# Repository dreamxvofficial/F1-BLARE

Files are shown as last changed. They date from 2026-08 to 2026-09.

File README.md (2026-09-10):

# F1 BLARE 🏎️⏰

## Inspiration

I wanted to make a BLARE alarm clock, but I didn't want it to look like a normal alarm clock.

Since I really like Formula 1, I decided to design the enclosure around the shape and layout of an F1 steering wheel. The goal was to make something that looks like a small racing control system while still functioning as a practical alarm clock.

The display is placed in the center like the display on an F1 steering wheel, with four buttons around it for controlling the clock and alarms.

The four buttons are used for:

- `+`
- `Set Alarm / Stop Alarm`
- `-`
- `Change Screen`

There are four screens: the normal clock and three different alarm screens.

### Challenges

This was my first time making a PCB and working with KiCad, so there were quite a few things I had to figure out.

I had to learn how to make the schematic, assign footprints, route the PCB, check it with DRC and add 3D models.

One of the biggest challenges was designing the PCB so that all the components, buttons and display connections would fit into a compact enclosure.

I originally planned to use an F1 car model as part of the enclosure, but I changed the design so that the enclosure itself is F1-inspired and can be designed directly as a proper CAD model. This makes the final design easier to manufacture and 3D print.

### Specifications

BOM:

- 1x Seeed XIAO ESP32-C3
- 4x Cherry MX-style switches
- 1x 2.25" TFT display
- 1x 3.3V piezo buzzer
- 1x 8-pin connector for the display
- 8x female-female jumper wires
- 4x M3x8 screws
- 4x M3x16 screws
- 8x M3 heatset inserts

Others:

- Arduino firmware
- Custom PCB
- Custom F1 steering-wheel-inspired enclosure
- 3D printed enclosure

### How it works

The main screen shows the current time.

Pressing the fourth button changes between the clock and the three alarm screens.

On an alarm screen:

- `+` increases the alarm time
- `-` decreases the alarm time
- `Set Alarm` enables/disables the alarm

When an alarm goes off, the buzzer plays until the user presses the alarm button.

The enclosure is designed around an F1 steering wheel layout, with the TFT display positioned in the center and the four physical controls placed around it.

### Schematic

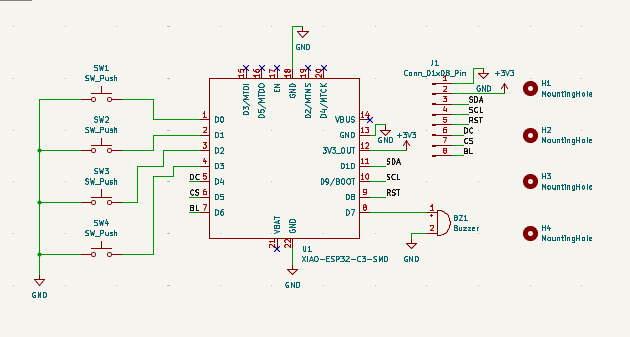
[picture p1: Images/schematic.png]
Schematic


### PCB

| PCB | 3D Model |
| --- | --- |
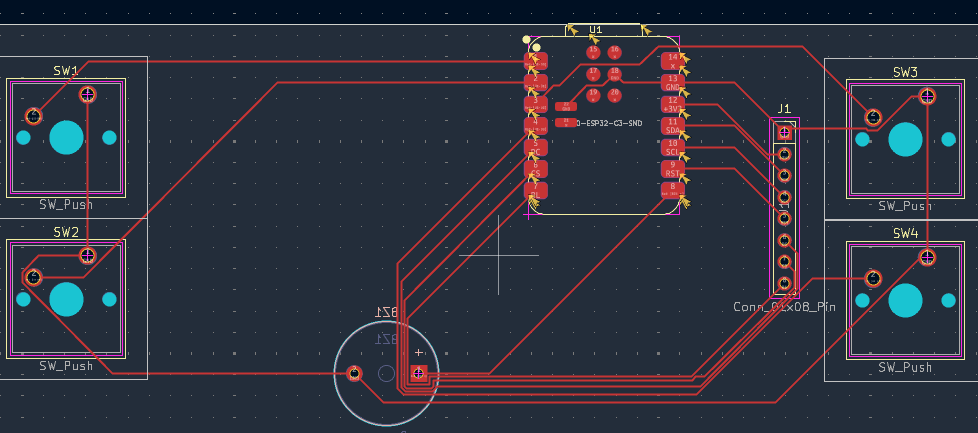
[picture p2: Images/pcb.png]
PCB
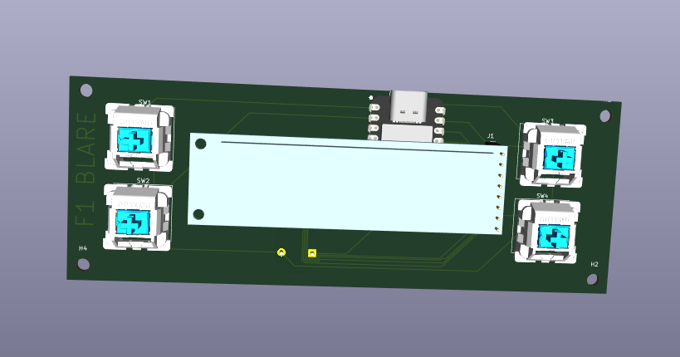
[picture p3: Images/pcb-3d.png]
3D PCB
|  |  |

### Case

The PCB will be mounted inside a custom 3D-printed enclosure inspired by an F1 steering wheel.

The 2.25" TFT display is positioned in the center of the front panel, with the four buttons arranged around it for easy access.

The enclosure will use rounded edges, racing-inspired shapes and details while keeping the internal geometry practical for 3D printing.

Unlike using an imported F1 car STL, the enclosure itself is designed as a proper CAD model so that the dimensions can be matched to the PCB and components.

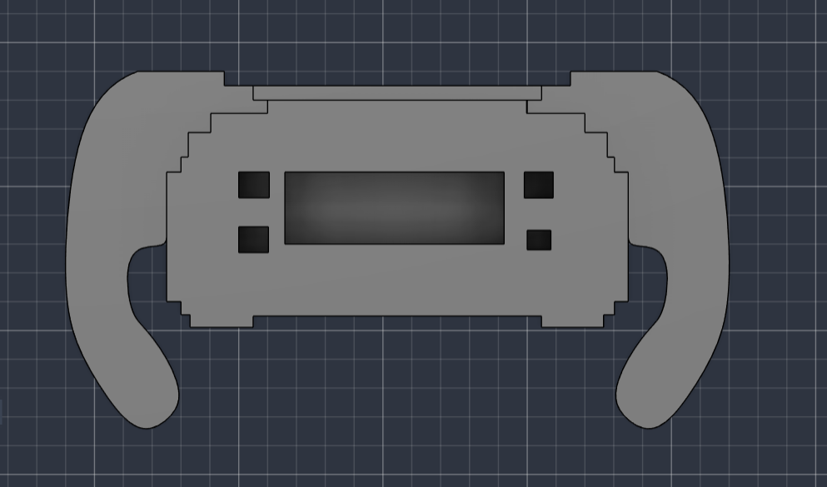
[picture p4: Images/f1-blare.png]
F1 BLARE

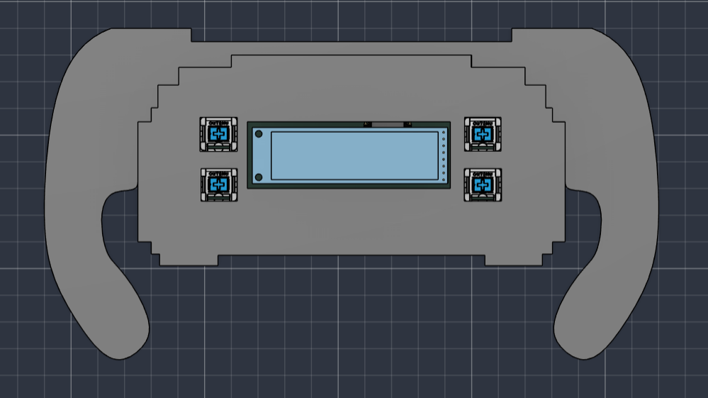
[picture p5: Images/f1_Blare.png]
F1 BLARE


### Firmware

The firmware is written using Arduino IDE and runs on the XIAO ESP32-C3.

The TFT display is controlled using the Adafruit GFX and ST7789 libraries.

The firmware handles:

- Digital clock display
- Three independent alarms
- Alarm time adjustment
- Alarm enable/disable
- Buzzer control
- Screen switching

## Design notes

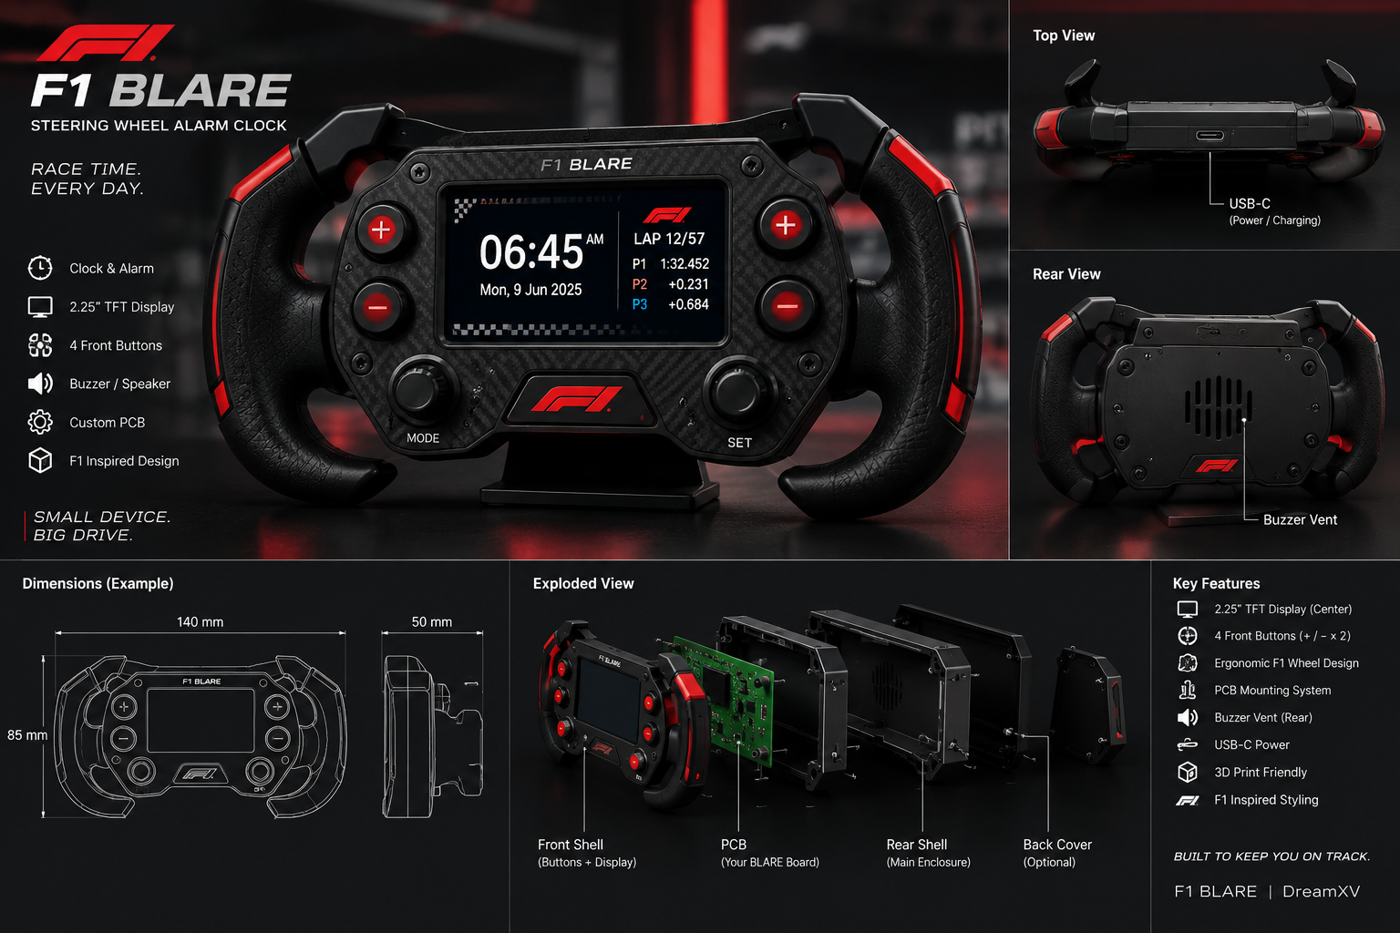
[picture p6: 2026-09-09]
Images/inspo.png

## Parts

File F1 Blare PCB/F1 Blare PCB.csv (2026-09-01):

Reference | Qty | Value | DNP | Exclude from BOM | Exclude from Board | Exclude from Simulation | Exclude from Position Files | Footprint | Datasheet
BZ1 | 1 | Buzzer |  |  |  |  | ${EXCLUDE_FROM_POS_FILES} | Buzzer_Beeper:Buzzer_12x9.5RM7.6
J1 | 1 | Conn_01x08_Pin |  |  |  |  | ${EXCLUDE_FROM_POS_FILES} | Connector_PinSocket_2.54mm:PinSocket_1x08_P2.54mm_Vertical
SW1,SW2,SW3,SW4 | 4 | SW_Push |  |  |  |  | ${EXCLUDE_FROM_POS_FILES} | Button_Switch_Keyboard:SW_Cherry_MX_1.00u_PCB
U1 | 1 | XIAO-ESP32-C3-SMD |  |  |  |  | ${EXCLUDE_FROM_POS_FILES} | Seeed_Studio_XIAO_Series:XIAO-ESP32-C3-SMD

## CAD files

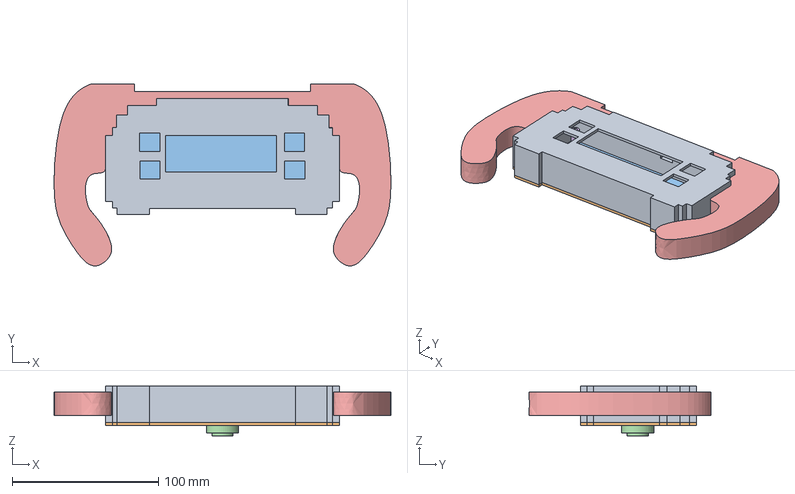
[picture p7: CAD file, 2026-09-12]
Production/CAD_CASE/F1 Blare PCB_Assembly.step
230.1 x 124.1 x 34.0 mm

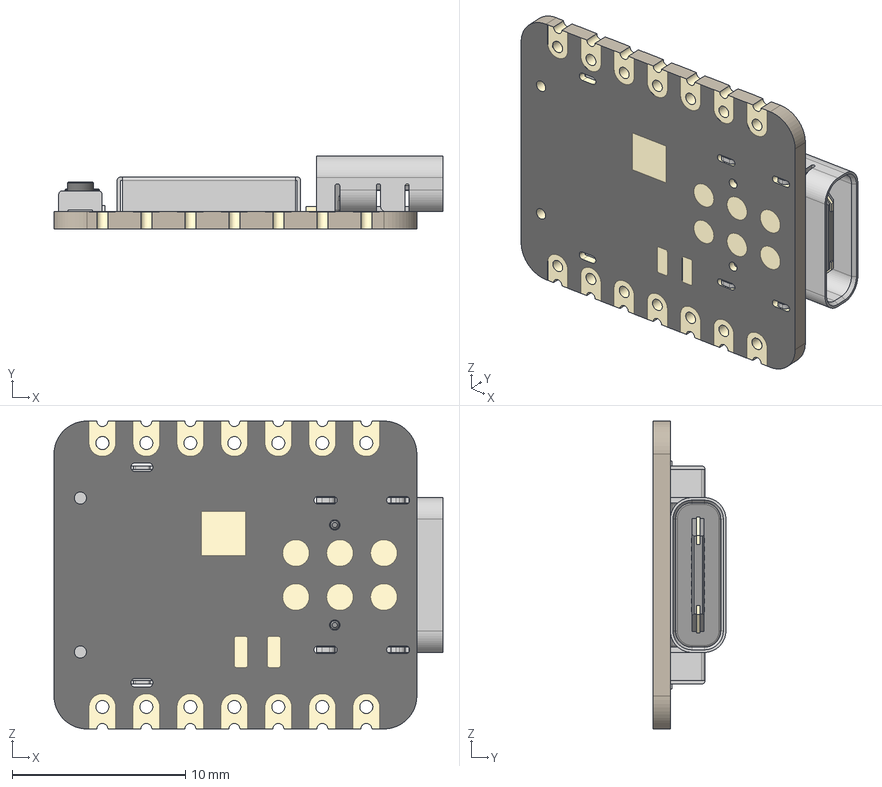
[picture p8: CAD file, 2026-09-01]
Additional Model/ESP 32 C3/Seeed Studio XIAO-ESP32-C3.step
22.5 x 4.21 x 17.8 mm
BOSS-EXTRUDE14_8_
BOSS-EXTRUDE7_4_
BOSS-EXTRUDE7_3_
BOSS-EXTRUDE14_4_
BOSS-EXTRUDE14_2_
BOSS-EXTRUDE14_11_
BOSS-EXTRUDE7_7_
BOSS-EXTRUDE14_9_
BOSS-EXTRUDE14_3_
BOSS-EXTRUDE14_7_
MIRROR2
BOSS-EXTRUDE14_5_
BOSS-EXTRUDE14_12_
BOSS-EXTRUDE7_8_
BOSS-EXTRUDE7_1_
BOSS-EXTRUDE14_10_
BOSS-EXTRUDE7_9_
BOSS-EXTRUDE14_6_
BOSS-EXTRUDE14_1_
BOSS-EXTRUDE7_6_
BOSS-EXTRUDE7_2_
CUT-EXTRUDE5
BOSS-EXTRUDE7_5_
U.FL Connector v1
Button (1) x 2
Shield

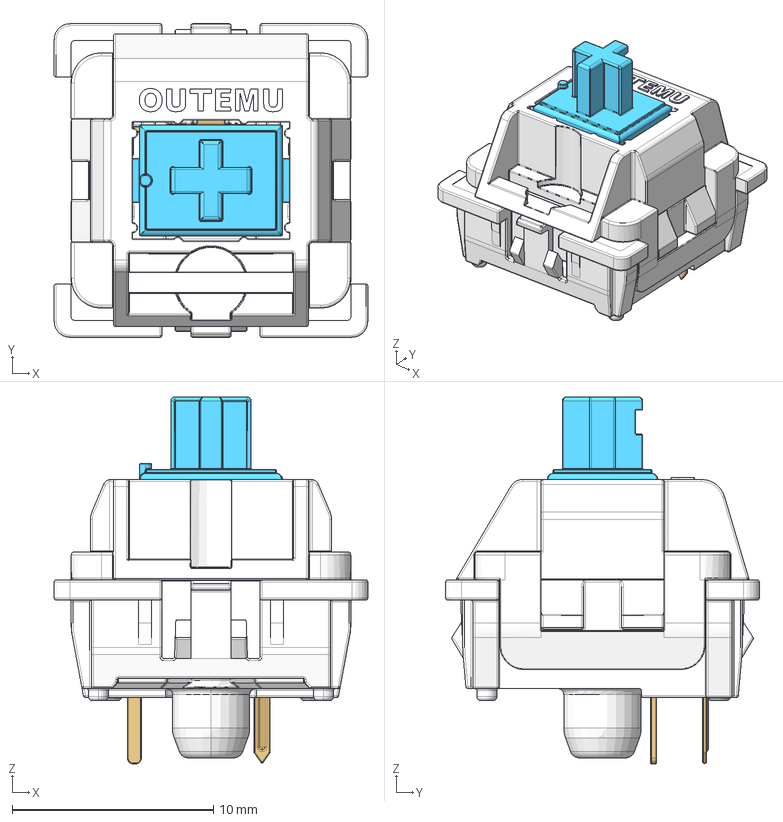
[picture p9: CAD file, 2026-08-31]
Additional Model/Key/mxstp.stp
15.6 x 15.6 x 18.2 mm
BOTT
PIN
SPRIN
CLICK
RET
TOP

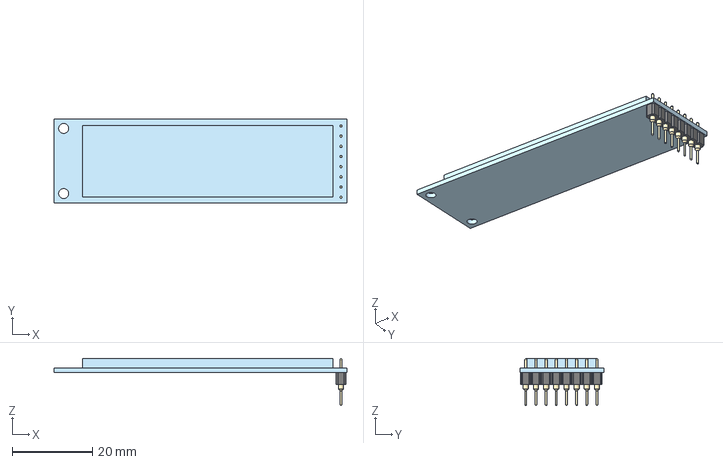
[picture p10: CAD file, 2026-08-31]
Additional Model/TFT Screen/Display with pins.step
73.2 x 21.1 x 11.8 mm
8 pin header v1_1 x 9

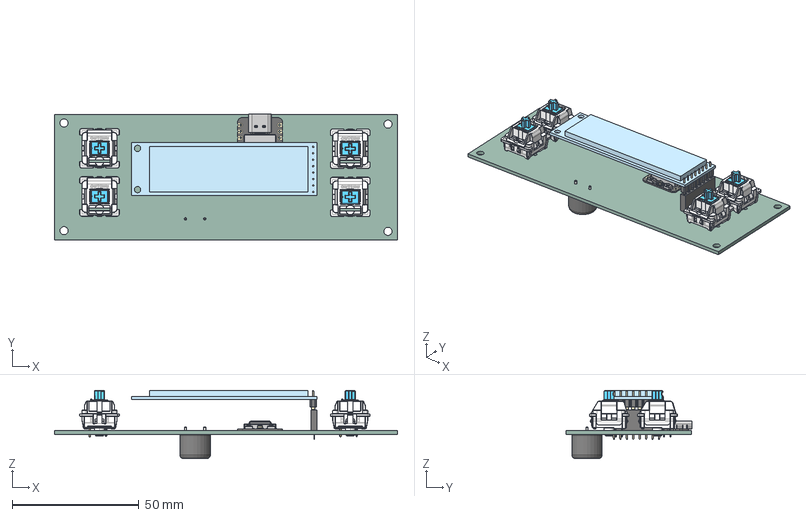
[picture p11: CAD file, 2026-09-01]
F1 Blare PCB/F1 Blare PCB.step
135.2 x 49.9 x 27.0 mm
PinSocket_1x08_P2.54mm_Vertical
8 pin header v1_1 x 9
BOTT x 4
PIN x 4
SPRIN x 4
CLICK x 4
RET x 4
TOP x 4
BOSS-EXTRUDE14_8_
BOSS-EXTRUDE7_4_
BOSS-EXTRUDE7_3_
BOSS-EXTRUDE14_4_
BOSS-EXTRUDE14_2_
BOSS-EXTRUDE14_11_
BOSS-EXTRUDE7_7_
BOSS-EXTRUDE14_9_
BOSS-EXTRUDE14_3_
BOSS-EXTRUDE14_7_
MIRROR2
BOSS-EXTRUDE14_5_
BOSS-EXTRUDE14_12_
BOSS-EXTRUDE7_8_
BOSS-EXTRUDE7_1_
BOSS-EXTRUDE14_10_
BOSS-EXTRUDE7_9_
BOSS-EXTRUDE14_6_
BOSS-EXTRUDE14_1_
BOSS-EXTRUDE7_6_
BOSS-EXTRUDE7_2_
CUT-EXTRUDE5
BOSS-EXTRUDE7_5_
U.FL Connector v1
Button (1) x 2
Shield
Buzzer_12x95RM76
F1 Blare PCB_PCB

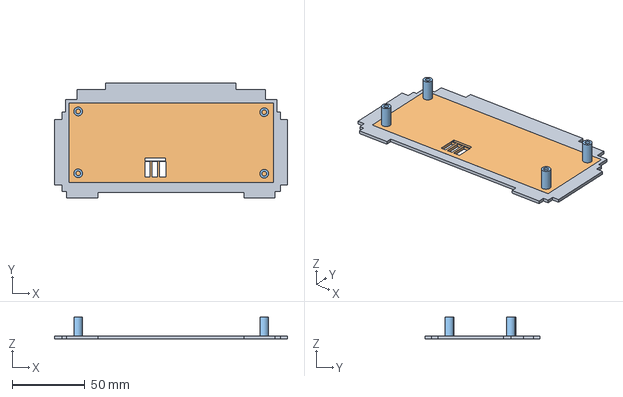
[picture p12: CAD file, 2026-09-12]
Production/CAD_CASE/F1 Blare PCB_Base.step
160.0 x 78.9 x 15.0 mm

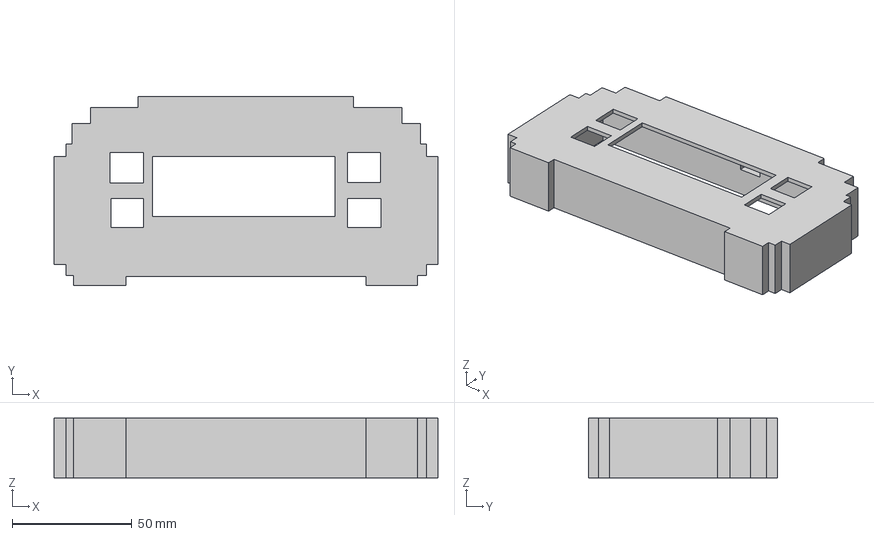
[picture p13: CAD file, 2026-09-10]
Production/CAD_CASE/F1 Blare PCB_Lid.step
160.0 x 78.9 x 25.0 mm

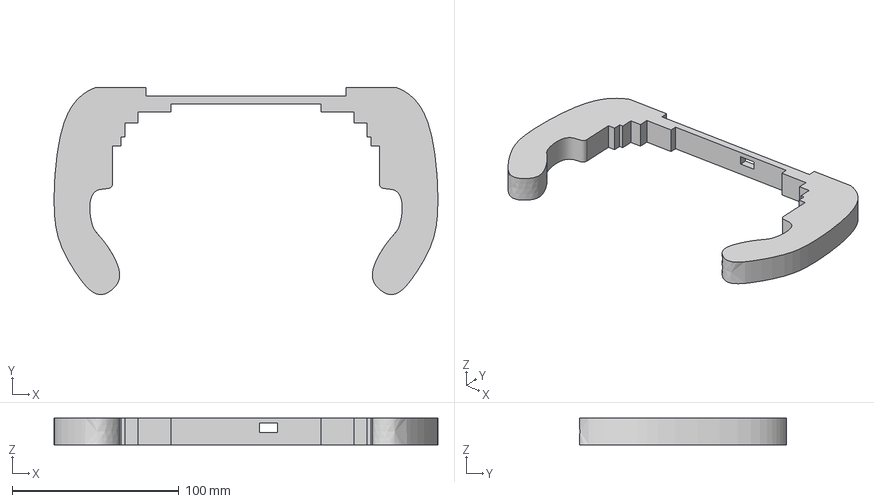
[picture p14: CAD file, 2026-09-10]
Production/CAD_CASE/F1 Blare PCB_Handel.step
230.1 x 124.1 x 16.0 mm

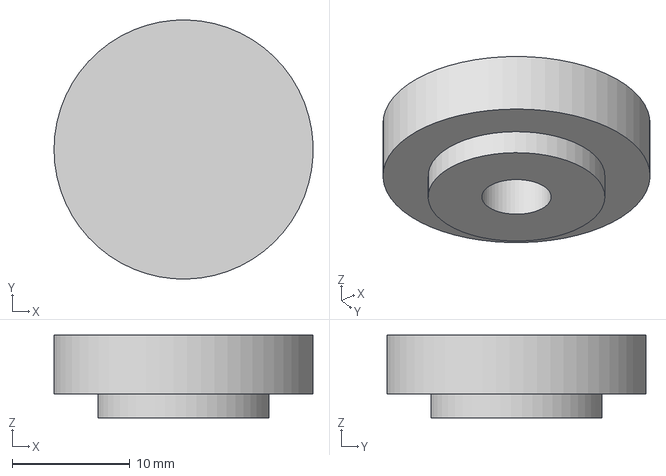
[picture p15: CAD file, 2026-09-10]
Production/CAD_CASE/F1 Blare PCB_Support_Wall.step
22.0 x 22.0 x 7.00 mm

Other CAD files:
Production/CAD_CASE/F1 Blare PCB_Supporter_Wall.step

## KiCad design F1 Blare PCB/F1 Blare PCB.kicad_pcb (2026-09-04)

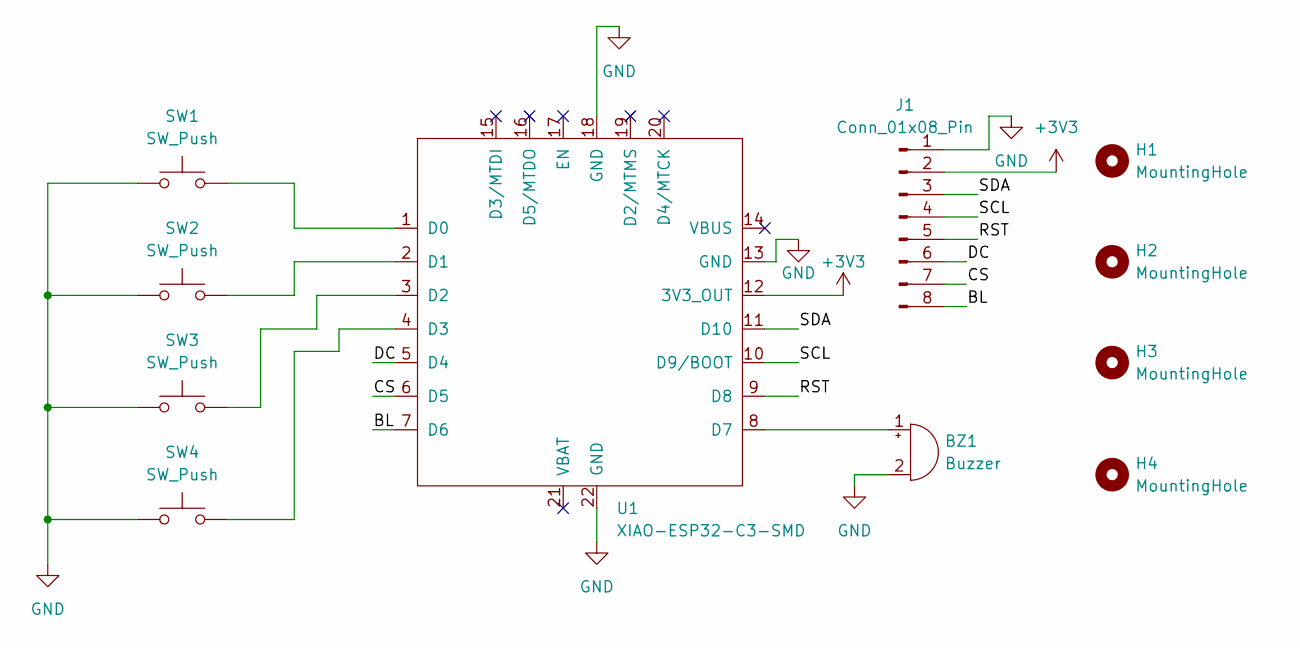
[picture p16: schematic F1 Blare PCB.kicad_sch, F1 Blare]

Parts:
BZ1: Buzzer; Buzzer_12x9.5RM7.6
H1, H2, H3, H4: MountingHole; MountingHole_3.2mm_M3
J1: Conn_01x08_Pin; PinSocket_1x08_P2.54mm_Vertical
SW1, SW2, SW3, SW4: SW_Push; SW_Cherry_MX_1.00u_PCB
U1: XIAO-ESP32-C3-SMD

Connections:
+3V3: J1.2, U1.12 (3V3_OUT)
/BL: J1.8, U1.7 (D6)
/CS: J1.7, U1.6 (D5)
/DC: J1.6, U1.5 (D4)
/RST: J1.5, U1.9 (D8)
/SCL: J1.4, U1.10 (D9/BOOT)
/SDA: J1.3, U1.11 (D10)
GND: BZ1.2 (-), J1.1, SW1.1, SW2.1, SW3.1, SW4.1, U1.13 (GND), U1.18 (GND), U1.22 (GND)
unnamed: BZ1.1 (+), U1.8 (D7)
unnamed: SW1.2, U1.1 (D0)
unnamed: SW2.2, U1.2 (D1)
unnamed: SW3.2, U1.3 (D2)
unnamed: SW4.2, U1.4 (D3)

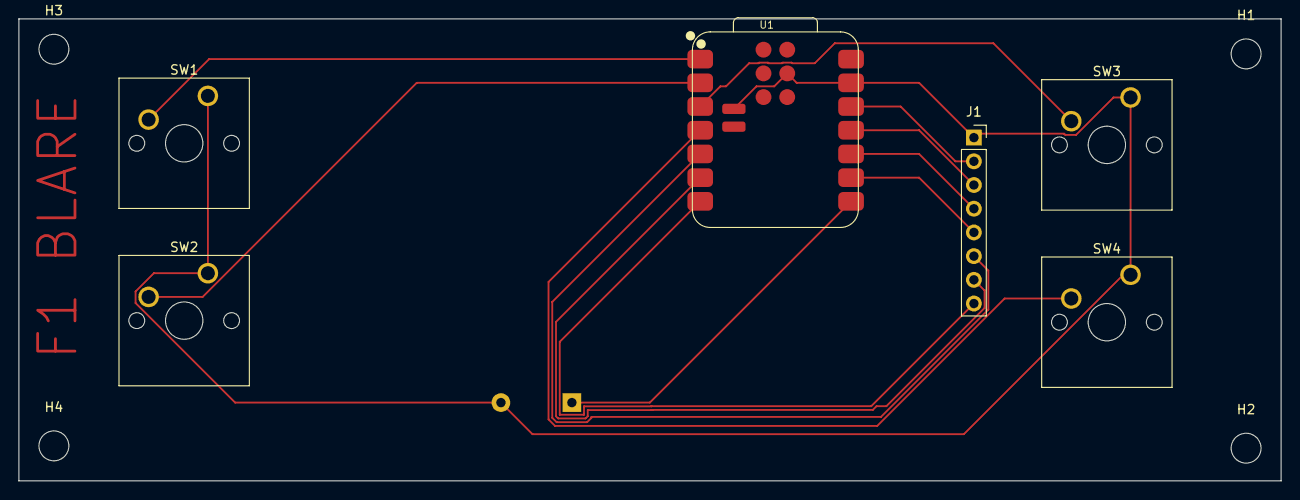
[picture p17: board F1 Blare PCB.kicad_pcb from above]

Board: 2 copper layers, 135.2 x 49.5 mm, 11 parts (1 on the bottom side), 13 nets.

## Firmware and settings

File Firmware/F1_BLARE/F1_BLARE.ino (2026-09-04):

#include <WiFi.h>
#include <time.h>
#include <Preferences.h>

#include <Adafruit_GFX.h>
#include <Adafruit_ST7789.h>
#include <SPI.h>


// WiFi

const char* ssid = "NA Bro";
const char* password = "*Not Visible in this code*";


// Display pins

#define TFT_SCLK 9
#define TFT_MOSI 10
#define TFT_RST  8
#define TFT_DC   4
#define TFT_CS   5
#define TFT_BL   6

Adafruit_ST7789 tft(
  TFT_CS,
  TFT_DC,
  TFT_MOSI,
  TFT_SCLK,
  TFT_RST
);

// Buttons

#define BUTTON_PLUS   3
#define BUTTON_SET    2
#define BUTTON_MINUS  1
#define BUTTON_SCREEN 0

// Buzzer

#define BUZZER_PIN 7


// Alarm data

struct Alarm {
  int hour;
  int minute;
  bool enabled;
};

Alarm alarms[3];


// Other variables

Preferences preferences;
int currentScreen = 0;
bool editingAlarm = false;
int editingAlarmNumber = 0;
unsigned long lastDisplayUpdate = 0;
unsigned long lastButtonTime = 0;
bool alarmRinging = false;
int ringingAlarm = -1;
unsigned long alarmStartTime = 0;


// Button helper

bool buttonPressed(int pin) {
  if (digitalRead(pin) == LOW) {

    if (millis() - lastButtonTime > 180) {
      lastButtonTime = millis();

      while (digitalRead(pin) == LOW) {
        delay(5);
      }

      return true;
    }
  }

  return false;
}

// Load alarms

void loadAlarms() {

  preferences.begin("blare", true);

  for (int i = 0; i < 3; i++) {

    String hourKey = "h" + String(i);
    String minKey  = "m" + String(i);
    String onKey   = "e" + String(i);

    alarms[i].hour =
      preferences.getInt(hourKey.c_str(), 7);

    alarms[i].minute =
      preferences.getInt(minKey.c_str(), 0);

    alarms[i].enabled =
      preferences.getBool(onKey.c_str(), false);
  }

  preferences.end();
}


// Save one alarm

void saveAlarm(int number) {

  preferences.begin("blare", false);

  String hourKey = "h" + String(number);
  String minKey  = "m" + String(number);
  String onKey   = "e" + String(number);

  preferences.putInt(
    hourKey.c_str(),
    alarms[number].hour
  );

  preferences.putInt(
    minKey.c_str(),
    alarms[number].minute
  );

  preferences.putBool(
    onKey.c_str(),
    alarms[number].enabled
  );

  preferences.end();
}


// Get current time

void getCurrentTime(int &hour, int &minute, int &second) {

  struct tm timeinfo;

  if (!getLocalTime(&timeinfo)) {
    hour = 0;
    minute = 0;
    second = 0;
    return;
  }

  hour = timeinfo.tm_hour;
  minute = timeinfo.tm_min;
  second = timeinfo.tm_sec;
}

// Draw normal clock

void showClock() {

  int hour;
  int minute;
  int second;

  getCurrentTime(hour, minute, second);

  char timeText[10];

  sprintf(
    timeText,
    "%02d:%02d",
    hour,
    minute
  );

  tft.fillScreen(ST77XX_BLACK);

  tft.setTextColor(ST77XX_WHITE);
  tft.setTextSize(6);

  tft.setCursor(20, 5);

  tft.print(timeText);

  // Small seconds display
  tft.setTextSize(2);

  tft.setCursor(125, 58);

  char secText[5];

  sprintf(secText, "%02d", second);

  tft.print(secText);

  tft.setTextSize(1);

  tft.setCursor(5, 5);
  tft.print("BLARE");
}


// Show alarm screen

void showAlarm(int number) {

  tft.fillScreen(ST77XX_BLACK);

  tft.setTextColor(ST77XX_WHITE);

  // Alarm NO
  tft.setTextSize(2);

  tft.setCursor(5, 3);

  tft.print("ALARM ");
  tft.print(number + 1);


  // Alarm time
  tft.setTextSize(5);

  tft.setCursor(35, 20);

  char alarmText[10];

  sprintf(
    alarmText,
    "%02d:%02d",
    alarms[number].hour,
    alarms[number].minute
  );

  tft.print(alarmText);


  // Status
  tft.setTextSize(2);

  tft.setCursor(105, 62);

  if (alarms[number].enabled) {
    tft.setTextColor(ST77XX_GREEN);
    tft.print("ON");
  }
  else {
    tft.setTextColor(ST77XX_RED);
    tft.print("OFF");
  }


  // Editing message
  if (editingAlarm &&
      editingAlarmNumber == number) {

    tft.setTextColor(ST77XX_WHITE);

    tft.setTextSize(1);

    tft.setCursor(5, 65);

    tft.print("+/- CHANGE   SET SAVE");
  }
}


// Show ringing screen

void showAlarmRinging() {

  tft.fillScreen(ST77XX_RED);

  tft.setTextColor(ST77XX_WHITE);

  tft.setTextSize(4);

  tft.setCursor(35, 10);

  tft.print("ALARM!");

  tft.setTextSize(2);

  tft.setCursor(40, 55);

  tft.print("PRESS SET");

  tft.setCursor(40, 70);

  tft.print("TO STOP");
}

// Start buzzer

void startAlarm(int number) {

  alarmRinging = true;
  ringingAlarm = number;

  alarmStartTime = millis();

  tone(BUZZER_PIN, 2000);

  showAlarmRinging();
}


// Stop buzzer

void stopAlarm() {

  noTone(BUZZER_PIN);

  alarmRinging = false;

  if (ringingAlarm >= 0) {

    // Turn this alarm off after
    alarms[ringingAlarm].enabled = false;

    saveAlarm(ringingAlarm);
  }

  ringingAlarm = -1;

  currentScreen = 0;

  showClock();
}


// Check alarms

void checkAlarms() {

  if (alarmRinging) {
    return;
  }

  int hour;
  int minute;
  int second;

  getCurrentTime(hour, minute, second);


  // Only check at start of minute
  if (second != 0) {
    return;
  }


  for (int i = 0; i < 3; i++) {

    if (!alarms[i].enabled) {
      continue;
    }

    if (alarms[i].hour == hour &&
        alarms[i].minute == minute) {

      startAlarm(i);

      break;
    }
  }
}


// Change alarm time

void increaseAlarm() {

  alarms[editingAlarmNumber].minute += 1;

  if (alarms[editingAlarmNumber].minute >= 60) {

    alarms[editingAlarmNumber].minute = 0;

    alarms[editingAlarmNumber].hour += 1;

    if (alarms[editingAlarmNumber].hour >= 24) {
      alarms[editingAlarmNumber].hour = 0;
    }
  }
}


void decreaseAlarm() {

  alarms[editingAlarmNumber].minute -= 1;

  if (alarms[editingAlarmNumber].minute < 0) {

    alarms[editingAlarmNumber].minute = 59;

    alarms[editingAlarmNumber].hour -= 1;

    if (alarms[editingAlarmNumber].hour < 0) {
      alarms[editingAlarmNumber].hour = 23;
    }
  }
}


// Handle buttons

void handleButtons() {


  // =======================
  // If alarm is ringing
  // =======================

  if (alarmRinging) {

    if (buttonPressed(BUTTON_SET)) {
      stopAlarm();
    }

    return;
  }


  // Change screen

  if (buttonPressed(BUTTON_SCREEN)) {

    // If currently editing, don't change screen
    if (!editingAlarm) {

      currentScreen++;

      if (currentScreen > 3) {
        currentScreen = 0;
      }

      if (currentScreen == 0) {
        showClock();
      }
      else {
        showAlarm(currentScreen - 1);
      }
    }

    return;
  }

  // Normal clock screen

  if (currentScreen == 0) {

    // Buttons don't change clock
    // on the main screen

    return;
  }

  // Alarm screen

  int alarmNumber = currentScreen - 1;


  // SET button

  if (buttonPressed(BUTTON_SET)) {

    if (!editingAlarm) {

      // Start editing
      editingAlarm = true;
      editingAlarmNumber = alarmNumber;

      showAlarm(alarmNumber);

    }
    else {

      // Save alarm
      alarms[alarmNumber].enabled = true;

      saveAlarm(alarmNumber);

      editingAlarm = false;

      showAlarm(alarmNumber);
    }

    return;
  }


  // + button

  if (editingAlarm &&
      buttonPressed(BUTTON_PLUS)) {

    increaseAlarm();

    showAlarm(alarmNumber);

    return;
  }


  // - button

  if (editingAlarm &&
      buttonPressed(BUTTON_MINUS)) {

    decreaseAlarm();

    showAlarm(alarmNumber);

    return;
  }
}


// Setup

void setup() {

  Serial.begin(115200);


  // Buttons
  pinMode(
    BUTTON_PLUS,
    INPUT_PULLUP
  );

  pinMode(
    BUTTON_SET,
    INPUT_PULLUP
  );

  pinMode(
    BUTTON_MINUS,
    INPUT_PULLUP
  );

  pinMode(
    BUTTON_SCREEN,
    INPUT_PULLUP
  );


  // Buzzer
  pinMode(
    BUZZER_PIN,
    OUTPUT
  );

  noTone(BUZZER_PIN);


  // Display backlight
  pinMode(
    TFT_BL,
    OUTPUT
  );

  digitalWrite(
    TFT_BL,
    LOW
  );


  // Display
  tft.init(76, 284);

  tft.setOffsets(82, 18);

  tft.invertDisplay(false);

  tft.setRotation(1);

  tft.fillScreen(ST77XX_BLACK);


  // Starting message
  tft.setTextColor(ST77XX_WHITE);

  tft.setTextSize(2);

  tft.setCursor(35, 25);

  tft.print("BLARE");

  delay(1000);


  // Connect WiFi

  tft.fillScreen(ST77XX_BLACK);

  tft.setCursor(20, 25);

  tft.print("WiFi...");

  WiFi.begin(
    ssid,
    password
  );

  int tries = 0;

  while (
    WiFi.status() != WL_CONNECTED &&
    tries < 30
  ) {

    delay(500);

    Serial.print(".");

    tries++;
  }


  // NTP time

  if (WiFi.status() == WL_CONNECTED) {

    Serial.println();

    Serial.println(
      "WiFi connected"
    );


    // India timezone
    configTime(
      19800,
      0,
      "pool.ntp.org",
      "time.nist.gov"
    );

    tft.fillScreen(ST77XX_BLACK);

    tft.setCursor(20, 25);

    tft.print("SYNC TIME");

    delay(1500);
  }
  else {

    Serial.println(
      "WiFi failed"
    );

    tft.fillScreen(ST77XX_BLACK);

    tft.setCursor(20, 25);

    tft.print("NO WIFI");

    delay(1500);
  }


  // Load saved alarm
  loadAlarms();


  // Start clk
  currentScreen = 0;

  showClock();
}

// Main loop

void loop() {

  handleButtons();

  checkAlarms();


  // Updt clk a sec
  if (
    currentScreen == 0 &&
    !editingAlarm &&
    !alarmRinging
  ) {

    if (
      millis() - lastDisplayUpdate >= 1000
    ) {

      lastDisplayUpdate = millis();

      showClock();
    }
  }


  // Keep Screen Updt
  if (
    currentScreen > 0 &&
    !alarmRinging
  ) {

    if (
      millis() - lastDisplayUpdate >= 1000
    ) {

      lastDisplayUpdate = millis();

      showAlarm(
        currentScreen - 1
      );
    }
  }


  // Stop 2 mins
  if (
    alarmRinging &&
    millis() - alarmStartTime >= 120000
  ) {

    stopAlarm();
  }


  delay(10);
}

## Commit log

2026-08-31 KICAD Schematic & PCB Design
    [Display with pins.step, F1 Blare PCB.step]
2026-08-31 Final Gerber File and PCB
    [F1 Blare PCB-B_Cu.gbr, F1 Blare PCB-B_Mask.gbr, F1 Blare PCB-B_Paste.gbr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]
2026-09-01 PCB Finalization & CAD Design
    [Display with pins.step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]
2026-09-09 Final CAD
    [F1 BLARE CAD_LID.step, F1 Blare PCB_Base.step, F1 Blare PCB_Handel.step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]
2026-09-10 F1 CAD Design Finalization
    [F1 Blare PCB_Assembly.step, F1 Blare PCB_Base.step, F1 Blare PCB_Handel.step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]
2026-09-10 FOrgot to add Charging port
    [F1 Blare PCB_Assembly.step, F1 Blare PCB_Base.step, F1 Blare PCB_Handel.step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]
2026-09-10 Final Cad Forgot Charger
    [F1 Blare PCB_Assembly.step, F1 Blare PCB_Base.step, F1 Blare PCB_Handel.step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]
2026-09-12 Chnaged Screw
    [F1 Blare PCB_Assembly.step, F1 Blare PCB_Base.step]
